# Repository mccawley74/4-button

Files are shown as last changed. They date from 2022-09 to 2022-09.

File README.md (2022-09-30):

# 4-button
A four button box for attaching to Thrustmaster MFD's
# DRAKE
## Drake 4-button box 1.0

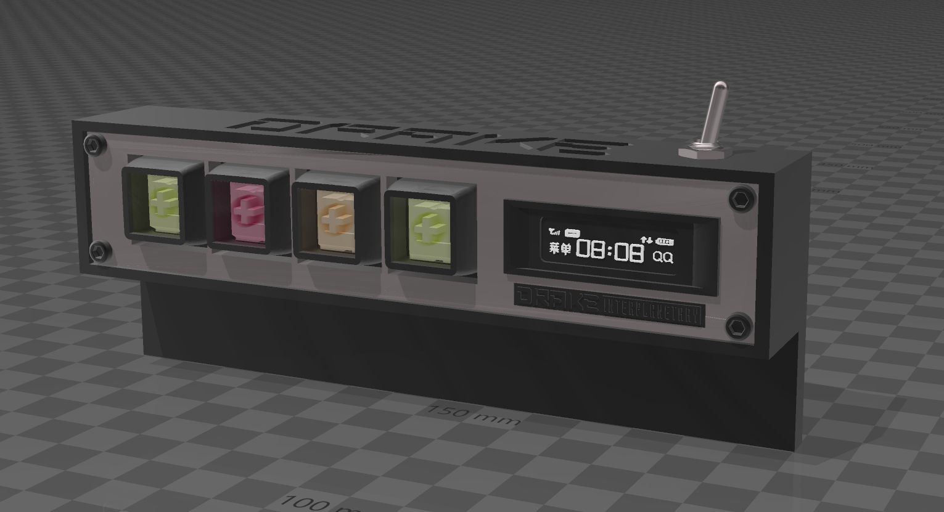
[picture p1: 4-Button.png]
Button Box


This is the code for the windows HID 4-button box in the style of Star Citizen DRAKE design.

This box is the third design of DRAKE inspired button boxes.
This one is designed to fit atop the Thrustmaster MFD's

You can find the 3D printable files in this repo.

The box uses an Arduino pro micro, and while there is no wiring schematic, the following should be quite straight forward.
All pins are labled as to what they connect to. All buttons and switches are GPIO to ground.

## Arduino Pro Micro wiring diagram
```
                          +-----+
                 +--------| USB |-------+
                 |        +-----+       |
                 | [1] TX         [RAW] |
                 | [0] RX         [GND] |  Ground
         Ground  | [GND]          [RST] |
         Ground  | [GND]          [VCC] |  Voltage for OLED
       OLED SDA  | [2] SDA      A3 [21] |  L.E.D. key 1 (green)
       OLED SCL  | [3] SCL      A2 [20] |  L.E.D. key 2 (green)
    Input Key-1  | [4] A6       A1 [19] |  L.E.D. key 3 (green)
    Input Key-2  | [5]          A0 [18] |  L.E.D. key 4 (green)
    Input Key-3  | [6] A7     SCLK [15] |  L.E.D. key 1 (red)
    Input Key-4  | [7]        MISO [14] |  L.E.D. key 2 (red)
     Cmd Button  | [8] A8     MOSI [16] |  L.E.D. key 3 (red)
                 | [9] A9      A10 [10] |  L.E.D. key 4 (red)
                 |                      |
                 +----------------------+
```

The Box utilizes two color LED's, though you could opt to use just a single color.
The different color just allows for a blink in another color when pressed.

## Keyboard Emulation
The box operates as a Windowd Keyboard. Showing up in Windows as a simple keyboard

There are 5 buttons. Four keyboard keyswitches and one button of your choice.
The four keys will register as a single key press whem pressed. the fifth button switches
profiles.

## Mapping keys to Star Citizen
The key mapping is done by editing the file menumap.h there is a struct for the menu of the buttons

### Default mapping
The default mapping is three profiles. Each button press of button 5 will switch profiles.
1. Profile one. the first four items in keyMenu struct
2. Profile two. the fifth through eighth items in keyMenu struct
3. Profile three. the ninth to end keyMenu struct

Example code from memumap.h This maps the three profiles.
You can see that the struct holds the name to display on the OLED, and the keyboard key to press.

```
const OLEDMENU keyMenu[12] PROGMEM = {
  {"LANDING", "LIGHTS", 'l'},                                      // Menu one key 1
  {"VTOL", "MODE", 'k'},                                           // Menu one key 2
  {"LANDING", "GEAR", 'n'},                                        // Menu one key 3
  {"REQUEST", "LANDING", KEY_INSERT},                              // Menu one key 4
  {"OPEN", "MOBIGLAS", KEY_F1},                                    // Menu two key 1
  {"OPEN", "STARMAP", KEY_F2},                                     // Menu two key 2
  {"OPEN", "CHAT", KEY_F11},                                       // Menu two key 3
  {"OPEN", "COMMS", KEY_INSERT},                                   // Menu two key 4
  {"TOGGLE", "WEAPONS", 'p'},                                      // Menu Three key 1
  {"TOGGLE" ,"SHIELDS", 'o'},                                      // Menu Three key 2
  {"TOGGLE", "ENGINES", 'i'},                                      // Menu Three key 3
  {"TOGGLE", "POWER", 'u'},                                        // Menu Three key 4
};
```
<em>Feel free to edit and modify the structures to suit your specific mapping in Star Citizen </em>

### That's about it. Have fun and feel free to change up the code as you see fit. Have fun.

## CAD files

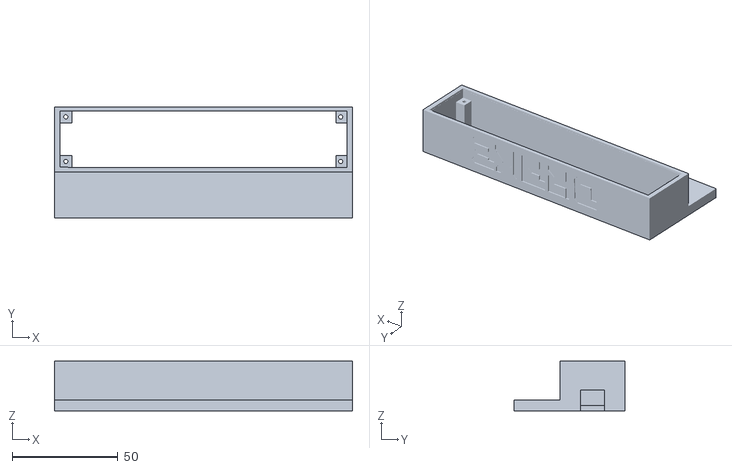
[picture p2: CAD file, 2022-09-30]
STL Files/main-chassis-opt.stl
141.0 x 52.7 x 23.6

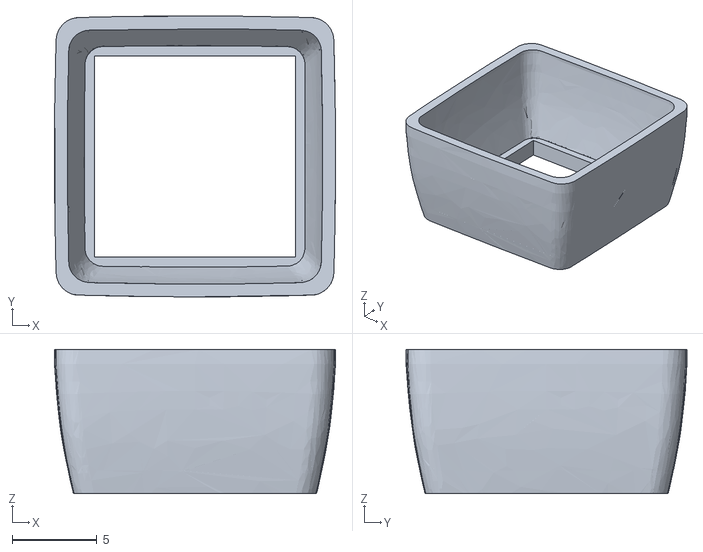
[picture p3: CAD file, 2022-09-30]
STL Files/key-outer.stl
16.6 x 16.6 x 8.50

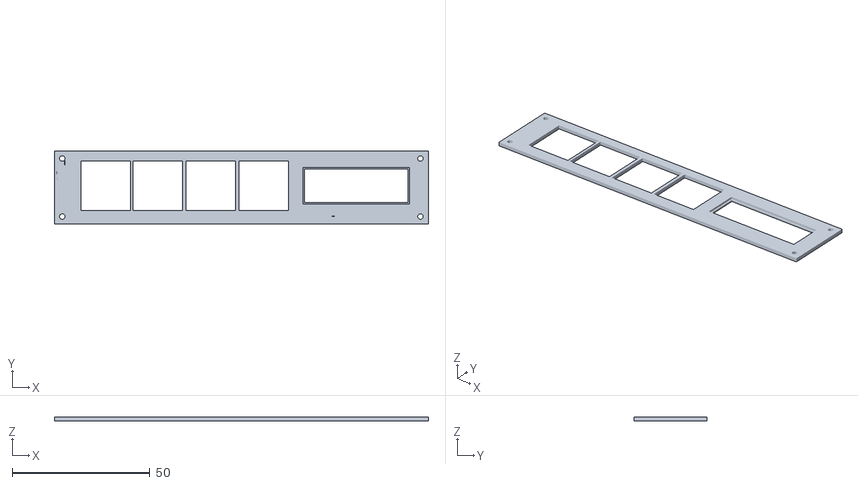
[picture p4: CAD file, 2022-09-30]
STL Files/front-plate.stl
135.8 x 26.7 x 1.50

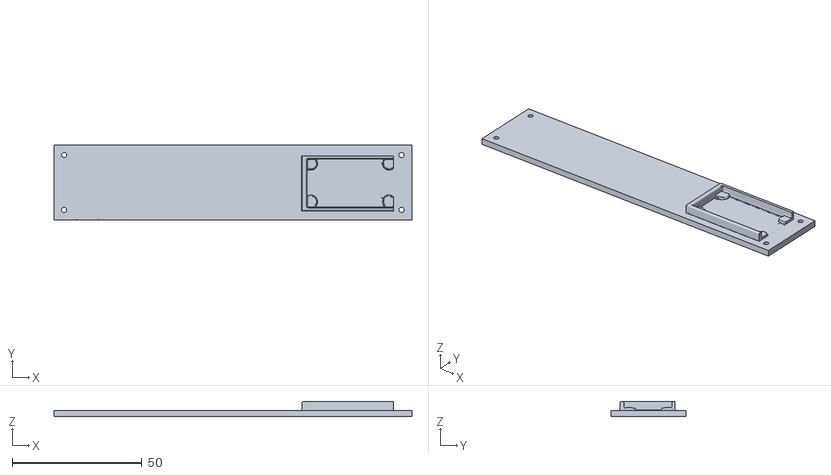
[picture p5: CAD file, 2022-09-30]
STL Files/rear-plate.stl
138.0 x 28.7 x 5.93

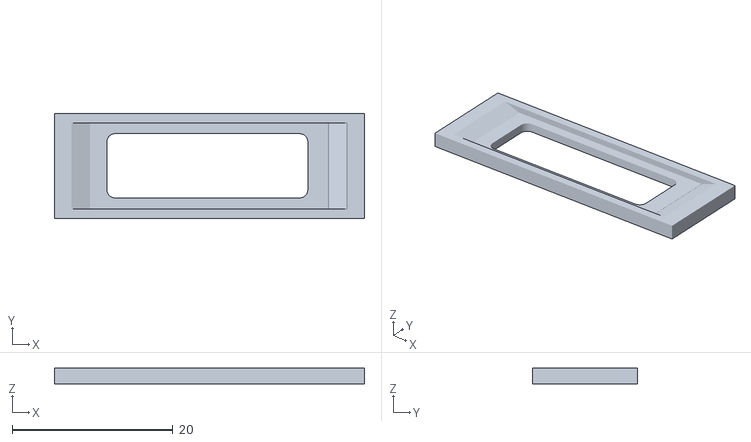
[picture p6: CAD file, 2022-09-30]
STL Files/oled-bezel.stl
38.6 x 13.1 x 1.98

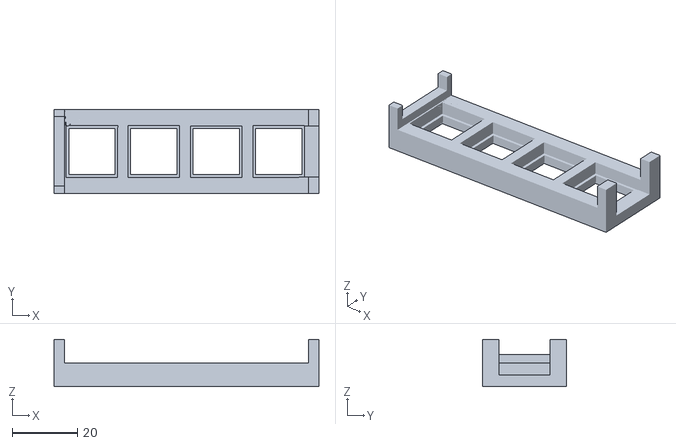
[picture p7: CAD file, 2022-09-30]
STL Files/keyswitch-frame.stl
81.2 x 25.8 x 14.5

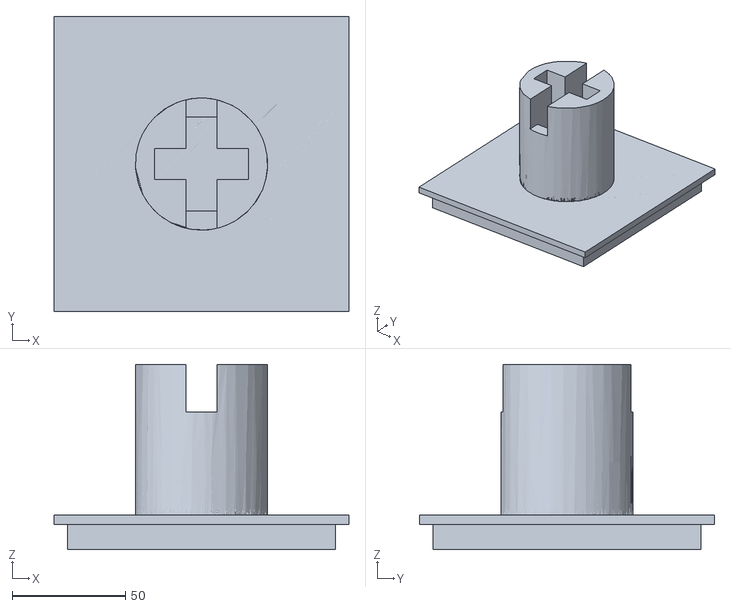
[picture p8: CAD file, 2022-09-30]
STL Files/key-center.stl
130.3 x 130.3 x 81.9

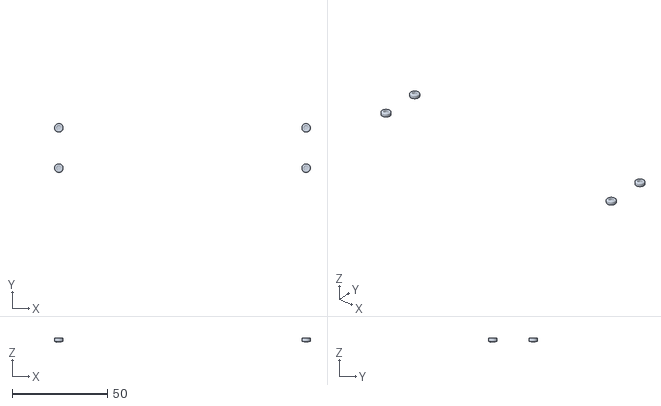
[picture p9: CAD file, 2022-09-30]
STL Files/screw-caps.stl
134.6 x 25.8 x 2.32

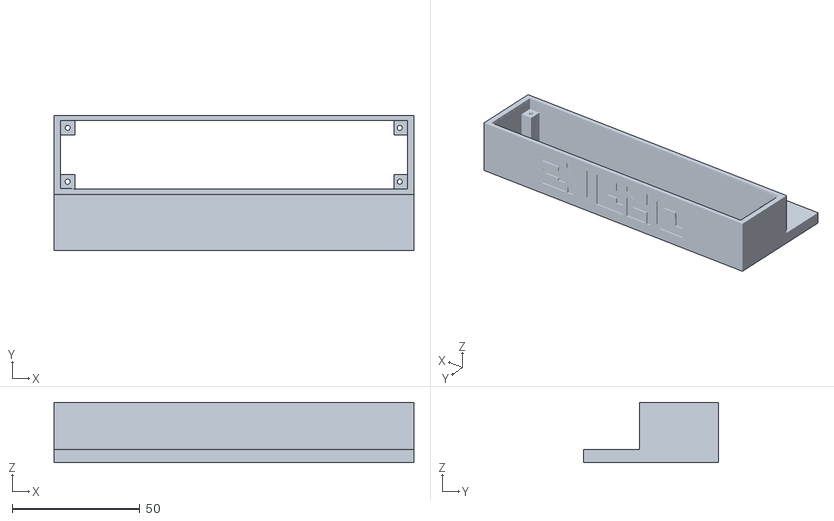
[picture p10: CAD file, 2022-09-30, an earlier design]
STL Files/archive/main-chassis.stl
141.0 x 52.7 x 23.6

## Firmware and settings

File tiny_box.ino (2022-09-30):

//-----------------------------------------------------------------------------
//  Tiny Gaming LLC, Hanna Button Box Thingy
//  Copyright (C) 2022 Tiny Gaming LLC  - All Rights Reserved 
//    
//  This file is part of {Hanna Button Box Thingy}
//  Unauthorized copying of this file, via any medium is strictly
//  prohibited proprietary and confidential
//
//  {Tiny Gaming Hanna Button Box Thingy} can not be copied and/or distributed
//  without the express permission of {Tiny Gaming LLC}
//
//  Authors: McCawley Mark
//  Version 1.3.0
//
//  Functions:
//  --------------------------------------
//  void read_drake_buttons(int polltime)
//  void read_drake_switch(int polltime)
//  void press_keyboard_key(int polltime)
//  void read_drake_keypad(int polltime)
//  void set_profile(int polltime)
//  void oled_write(String text)
//  void setup()
//  void loop()
//
//             Arduino Pro Micro wiring diagram
//           ____________________________________
//
//                          +-----+
//                 +--------| USB |-------+
//                 |        +-----+       |
//                 | [1] TX         [RAW] |
//                 | [0] RX         [GND] |  Ground
//         Ground  | [GND]          [RST] |
//         Ground  | [GND]          [VCC] |  Voltage for OLED
//       OLED SDA  | [2] SDA      A3 [21] |  L.E.D. key 1 (green)
//       OLED SCL  | [3] SCL      A2 [20] |  L.E.D. key 2 (green)
//    Input Key-1  | [4] A6       A1 [19] |  L.E.D. key 3 (green)
//    Input Key-2  | [5]          A0 [18] |  L.E.D. key 4 (green)
//    Input Key-3  | [6] A7     SCLK [15] |  L.E.D. key 1 (red)
//    Input Key-4  | [7]        MISO [14] |  L.E.D. key 2 (red)
//     Cmd Button  | [8] A8     MOSI [16] |  L.E.D. key 3 (red)
//                 | [9] A9      A10 [10] |  L.E.D. key 4 (red)
//                 |                      |
//                 +----------------------+
//
//  NOTE:
//  1. Switch One and Switch Five is each half of a 2-way switch, center to ground
//  2. All switches are connected from the arduino GPIO to ground with Internal pullups.
//  3. L.E.D key backlighting uses one 330ohm resistor per three L.E.Ds
//
//  4. This version of code uses two OLED screens. One side mounted 128x32
//     And onea top mounted 128x64. However they are both set to 128x64 and on
//     the same I2C address 0x3C [duplicated screens]
//     The plan was to have seperate screens, but the OLEDs I have are not I2C
//     address modifyable, plus it came out looking just fine afer some formatting.
//  
//         I2C OLED Display
//         0.91 Inch SSD1306
//         OLED 128x32
//         Address: 0x3C
//          _______________________
//         | |                   |*|
//         | | Oled Menu 128x32  |*|
//         |_|___________________|*|

//
//-----------------------------------------------------------------------------

// Include header files
#include <Keyboard.h>
#include <Adafruit_GFX.h>
#include <Adafruit_SSD1306.h>
#include <Wire.h>
#include <Bounce2.h>
#include <Arduino.h>
#include "menumap.h"

// Defines
#define HIGH 0x1
#define LOW  0x0
#define SCREEN_WIDTH 128
#define SCREEN_HEIGHT 64
#define LOGO_HEIGHT 16
#define OLED_RESET -1
#define LOGO_WIDTH 16
#define key_1 4
#define key_2 5
#define key_3 6
#define key_4 7
#define led_1_grn 21
#define led_2_grn 20
#define led_3_grn 19
#define led_4_grn 18
#define led_1_red 15
#define led_2_red 14
#define led_3_red 16
#define led_4_red 10
#define ctrl_btn 8

// Constant declarations
const byte ROWS = 3; // Matrix keypad three rows
const byte COLS = 3; // Matrix keypad three columns
const long LOOP_INTERVAL = 10;  // Polling rate for main loop
const long KEY_INTERVAL = 0; // Polling rate for LED brightness button
const unsigned long DISP_TIMEOUT = 300; // OLED refresh DISP_TIMEOUT

// Init variables other mix
int key_pressed;
int pin_array_grn [] {led_1_grn, led_2_grn, led_3_grn, led_4_grn,};
int pin_array_red [] {led_1_red, led_2_red, led_3_red, led_4_red};
unsigned long oled_cnt; // Counter for OLED text to timeout
bool key_update = false;
int cur_menu = 1;
String menu_name = "LANDING";

// Initialize an instance of Keypad and OLED screen
Adafruit_SSD1306 display(SCREEN_WIDTH, SCREEN_HEIGHT, &Wire, OLED_RESET);

// Instantiate an instance of a Bounce object for corresponding buttons
Bounce b_key_1 = Bounce();
Bounce b_key_2 = Bounce();
Bounce b_key_3 = Bounce();
Bounce b_key_4 = Bounce();
Bounce b_ctrl_1 = Bounce();

Blinker key_1_blink(led_1_grn);
Blinker key_2_blink(led_2_grn);
Blinker key_3_blink(led_3_grn);
Blinker key_4_blink(led_4_grn);

// The menu item each key accesses
int keymnu_1 = 0;
int keymnu_2 = 1;
int keymnu_3 = 2;
int keymnu_4 = 3;

/*!
 * @function    check_for_keypress
 * @abstract    Poll for button change.
 * @discussion  Writes text to OLED, and presses key
 * @param       polling delay in milliseconds
 * @result      void
*/
void check_for_keypress(int polltime)
{
  b_key_1.update();
  b_key_2.update();
  b_key_3.update();
  b_key_4.update();

  if (b_key_1.fell()) {
    memcpy_P(&menuSRAM, &keyMenu[keymnu_1], sizeof(OLEDMENU));
    key_update = true;
    key_pressed = 1;
  }
  if (b_key_2.fell()) {
    memcpy_P(&menuSRAM, &keyMenu[keymnu_2], sizeof(OLEDMENU));
    key_update = true;
    key_pressed = 2;
  }
  if (b_key_3.fell()) {    
    memcpy_P(&menuSRAM, &keyMenu[keymnu_3], sizeof(OLEDMENU));
    key_update = true;
    key_pressed = 3;
  }
  if (b_key_4.fell()) {
    memcpy_P(&menuSRAM, &keyMenu[keymnu_4], sizeof(OLEDMENU));
    key_update = true;
    key_pressed = 4;
  }

  // If any of the keys were pressed, update the OLED screen
  if(key_update) {
    oled_write_text(menuSRAM.name1, menuSRAM.name2);
    press_keyboard_key(menuSRAM.keyId);
    set_key_led(key_pressed, LOW);
    key_update = false;
    delay(50);
  }
  
  delay(polltime);
}

/*!
 * @function    check_command_key
 * @abstract    Poll for button change.
 * @discussion  Writes text to OLED, and presses key
 * @param       polling delay in milliseconds
 * @result      void
*/
void check_command_key(int polltime)
{
  b_ctrl_1.update();

  if (b_ctrl_1.fell()) {
    set_menu();

    switch (cur_menu) {
      case 1:
        keymnu_1 = 0;
        keymnu_2 = 1;
        keymnu_3 = 2;
        keymnu_4 = 3;        
        break;
      case 2:
        keymnu_1 = 4;
        keymnu_2 = 5;
        keymnu_3 = 6;
        keymnu_4 = 7;
        break;
      case 3:
        keymnu_1 = 8;
        keymnu_2 = 9;
        keymnu_3 = 10;
        keymnu_4 = 11;
        break;
    }
  }
  delay(polltime);
}


/*!
 * @function    set_menu(int key, uint8_t state)
 * @abstract    Set the key L.E.D color.
 * @discussion  Switch mode. Switch one and five is a two way switch
 * @param       key switch one state
 * @param       state switch five state
 * @result      void
*/
void set_menu()
{
  cur_menu++;
  if(cur_menu == 4){cur_menu = 1;}
  switch (cur_menu) {
    case 1:
      menu_name = "LANDING";
      break;
    case 2:
      menu_name = "COMMS";
      break;
    case 3:
      menu_name = "POWER";
      break;
  }
  oled_write_text(menu_name, "MENU:" + String(cur_menu));
}

/*!
 * @function    set_key_led(int key, uint8_t state)
 * @abstract    Set the key L.E.D color.
 * @discussion  Switch mode. Switch one and five is a two way switch
 * @param       key switch one state
 * @param       state switch five state
 * @result      void
*/
void set_key_led(int key, uint8_t state)
{
  if(key == 0) { // Default state all red ON, all green OFF
    for (int i=0; i<sizeof pin_array_grn/sizeof pin_array_grn[0]; i++) {
      digitalWrite(pin_array_grn[i], HIGH);
      digitalWrite(pin_array_red[i], LOW);
    }
  } else if(key == 5) { // Default state all green ON, all red OFF
    for (int i=0; i<sizeof pin_array_grn/sizeof pin_array_grn[0]; i++) {
      digitalWrite(pin_array_grn[i], LOW);
      digitalWrite(pin_array_red[i], HIGH);
    }
  } else { // Individual state
    switch (key) {
      case 1:
      digitalWrite(led_1_grn, LOW);
      digitalWrite(led_1_red, HIGH);
      key_1_blink.blinkOn = true;
      break;
    case 2:
      digitalWrite(led_2_grn, LOW);
      digitalWrite(led_2_red, HIGH);
      key_2_blink.blinkOn = true;
      break;
    case 3:
      digitalWrite(led_3_grn, LOW);
      digitalWrite(led_3_red, HIGH);
      key_3_blink.blinkOn = true;
      break;
    case 4:
      digitalWrite(led_4_grn, LOW);
      digitalWrite(led_4_red, HIGH);
      key_4_blink.blinkOn = true;
      break;
    default:
      // ON - Green
      // OFF - RED
      // Blink Green
      break;
    }
  }
}

/*!
 * @function    oled_write(String text)
 * @abstract    Write test to the OLED screen
 * @discussion  Send a string of text to the OLED screen
 * @param       String text: the text to write to screen
 * @result      void
*/
void oled_write_text(String text1, String text2)
{
  int font_width = SCREEN_WIDTH / 11;
  int start;
  
  display.clearDisplay(); // Clear OLED
  display.setTextColor(WHITE);

  display.setTextSize(4); // Font size
  display.setCursor(0, 20);
  display.println(String(cur_menu));

  // First line of the display
  display.setTextSize(2); // Font size
  start = (font_width - text1.length()+3) * 5;
  display.setCursor(start, 10);
  display.println(text1);
  
  // Second line of the display
  start = (font_width - text2.length()+3) * 5;
  display.setCursor(start, 42);
  display.println(text2);

  display.display(); // Write to screen
  oled_cnt = 0; // Incr text timeout
}

/*!
 * @function    press_keyboard_key
 * @abstract    press a key
 * @discussion  press a key on the keyboard
 * @param       char key: The key to press
 * @result      void
*/
void press_keyboard_key(char key)
{
  Keyboard.press(key);
  delay(50);
  Keyboard.release(key);
  delay(50);
}

/*
 * @function    setup
 * @abstract    Inital setup method
 * @discussion  Define pin pullups and set variables
 * @param       
 * @result      none
*/
void setup()
{
  Serial.begin(9600);
  Keyboard.begin();

  // Serial.print("void setup()");
  // Serial.println("Inital setup method");

  // Set internal pullups on buttons
  pinMode(key_1, INPUT_PULLUP);
  pinMode(key_2, INPUT_PULLUP);
  pinMode(key_3, INPUT_PULLUP);
  pinMode(key_4, INPUT_PULLUP);

  // Set initial state
  set_key_led(0, HIGH);

  // Set pin mode
  for (int i=0; i<sizeof pin_array_grn/sizeof pin_array_grn[0]; i++) {
    pinMode(pin_array_grn[i], OUTPUT);
  }
  for (int i=0; i<sizeof pin_array_red/sizeof pin_array_red[0]; i++) {
    pinMode(pin_array_red[i], OUTPUT);
  }
  pinMode(ctrl_btn, INPUT_PULLUP);

  // Attach debouncers to buttons
  b_key_1.attach(key_1, INPUT_PULLUP);
  b_key_2.attach(key_2, INPUT_PULLUP);
  b_key_3.attach(key_3, INPUT_PULLUP);
  b_key_4.attach(key_4, INPUT_PULLUP);
  b_ctrl_1.attach(ctrl_btn, INPUT_PULLUP);

  // Set button debounce intervals
  b_key_1.interval(5);
  b_key_2.interval(5);
  b_key_3.interval(5);
  b_key_4.interval(5);
  b_ctrl_1.interval(5);

  // SSD1306_SWITCHCAPVCC = generate display voltage from 3.3V internally
  if(!display.begin(SSD1306_SWITCHCAPVCC, 0x3C)) {
    Serial.println(F("SSD1306 allocation failed"));
    for(;;); // Don't proceed, loop forever
  }

  // Setup initial OLED display
  oled_cnt = 0;
  display.display();
  display.clearDisplay();
  display.drawBitmap(0, 4, drakeLogo, 128, 64, WHITE);
  display.display();

  // Start eachj  L.E.D blink object
  key_1_blink.begin(500, 500);
  key_2_blink.begin(500, 500);
  key_3_blink.begin(500, 500);
  key_4_blink.begin(500, 500);
}

/*!
 * @function    loop
 * @abstract    Main program loop.
 * @discussion  Polls for changes in switch, pad,  and button state.
 * @param       
 * @result      none
*/
void loop()
{
  // Poll for key press, and command button press
  check_for_keypress(KEY_INTERVAL);
  check_command_key(KEY_INTERVAL);
  key_1_blink.check();
  key_2_blink.check();
  key_3_blink.check();
  key_4_blink.check();
  
  // Text on OLED will timeout and return to this message
  if (oled_cnt >= DISP_TIMEOUT) {
    //display.clearDisplay();
    //display.drawBitmap(0, 4, drakeLogo, 128, 64, WHITE);
    //display.display();
    set_key_led(0, HIGH);
    oled_cnt = 0;
    key_1_blink.blinkOn = false;
    key_2_blink.blinkOn = false;
    key_3_blink.blinkOn = false;
    key_4_blink.blinkOn = false;
    // delay(1000);
    // oled_write_text("Drake", "DRAKE");
  }
  ++oled_cnt; // Increment text timeout
  delay(LOOP_INTERVAL);
}

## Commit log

2022-09-30 Need to add to folder `
    [front-plate.stl, key-center.stl, key-outer.stl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]
2022-09-30 Re-adding stl files in folder
    [front-plate.stl, key-center.stl, key-outer.stl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]
